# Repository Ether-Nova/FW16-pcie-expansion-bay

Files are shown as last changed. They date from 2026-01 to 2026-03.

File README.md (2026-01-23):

# FW16-pcie-expansion-bay
My goal for this project is to be able to connect any common pcie device to the framework 16. The expansion bay would include 75W power to the gen 4 x8 (4 x16 phisical size) slot and allow pcie extenders and aother devices to be connected to it. 
I am currently in the phase of tesing a covnertor for the 12V 75W bus.

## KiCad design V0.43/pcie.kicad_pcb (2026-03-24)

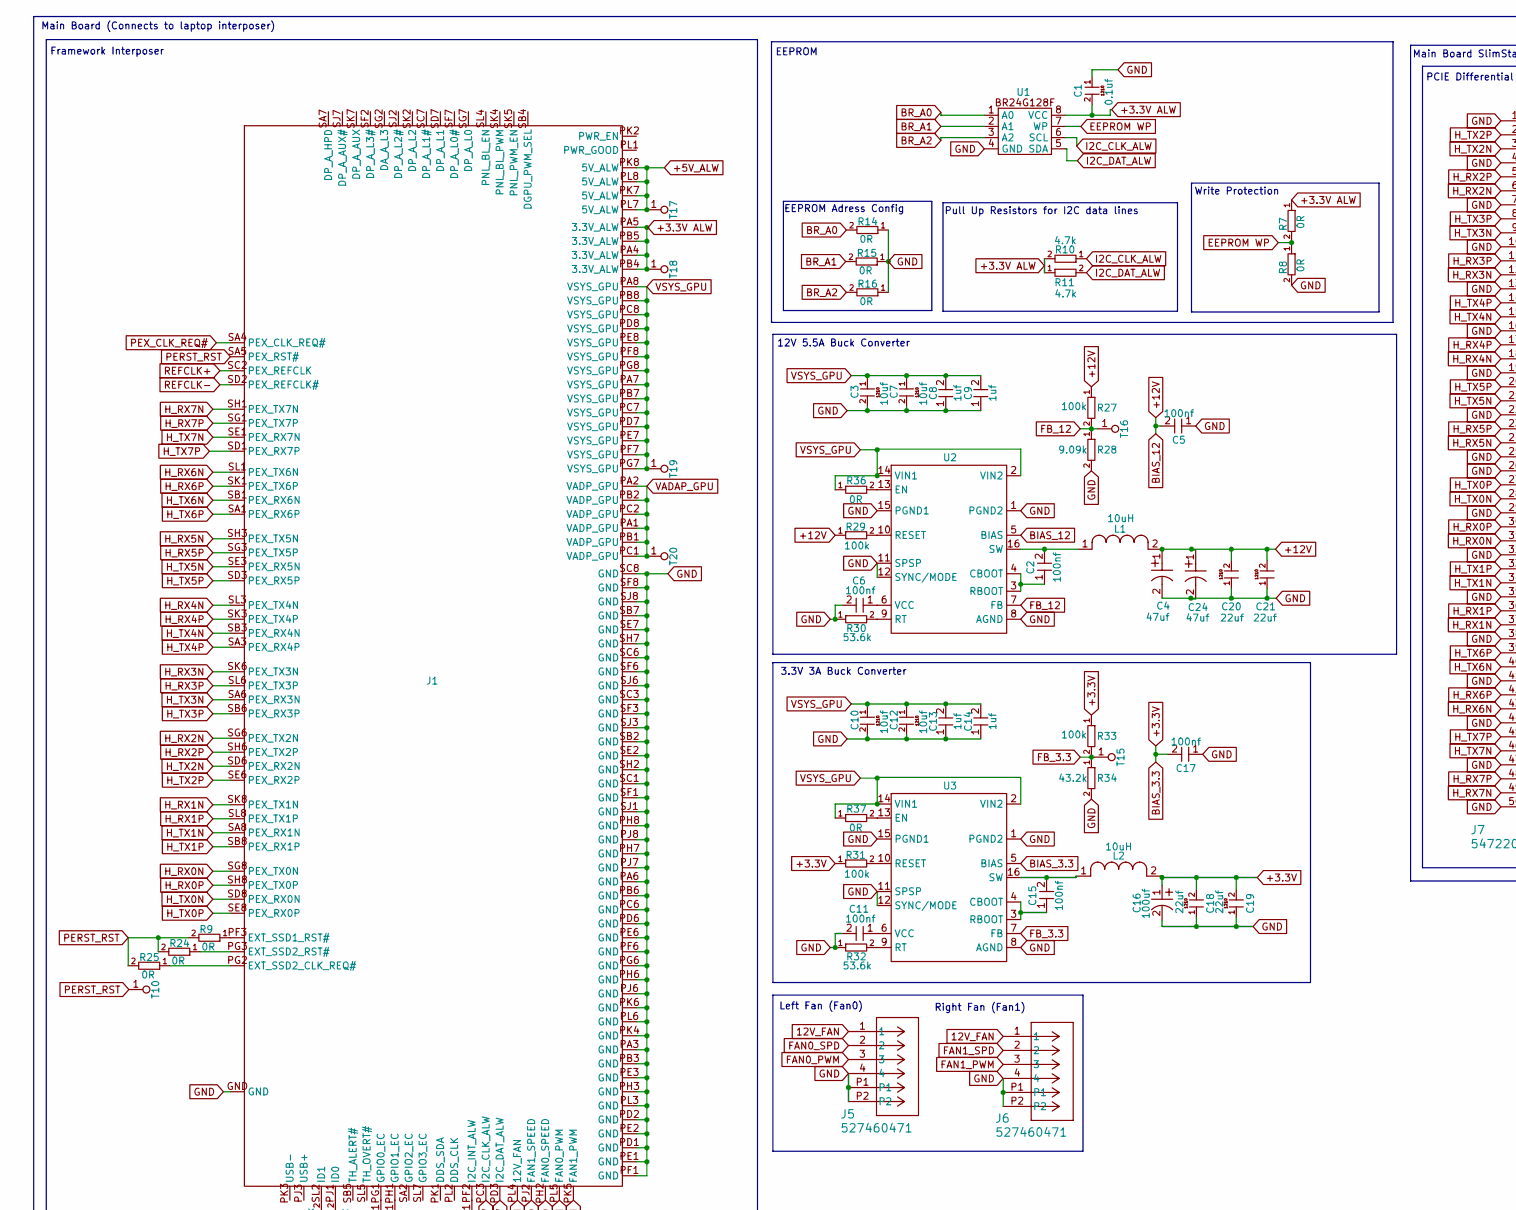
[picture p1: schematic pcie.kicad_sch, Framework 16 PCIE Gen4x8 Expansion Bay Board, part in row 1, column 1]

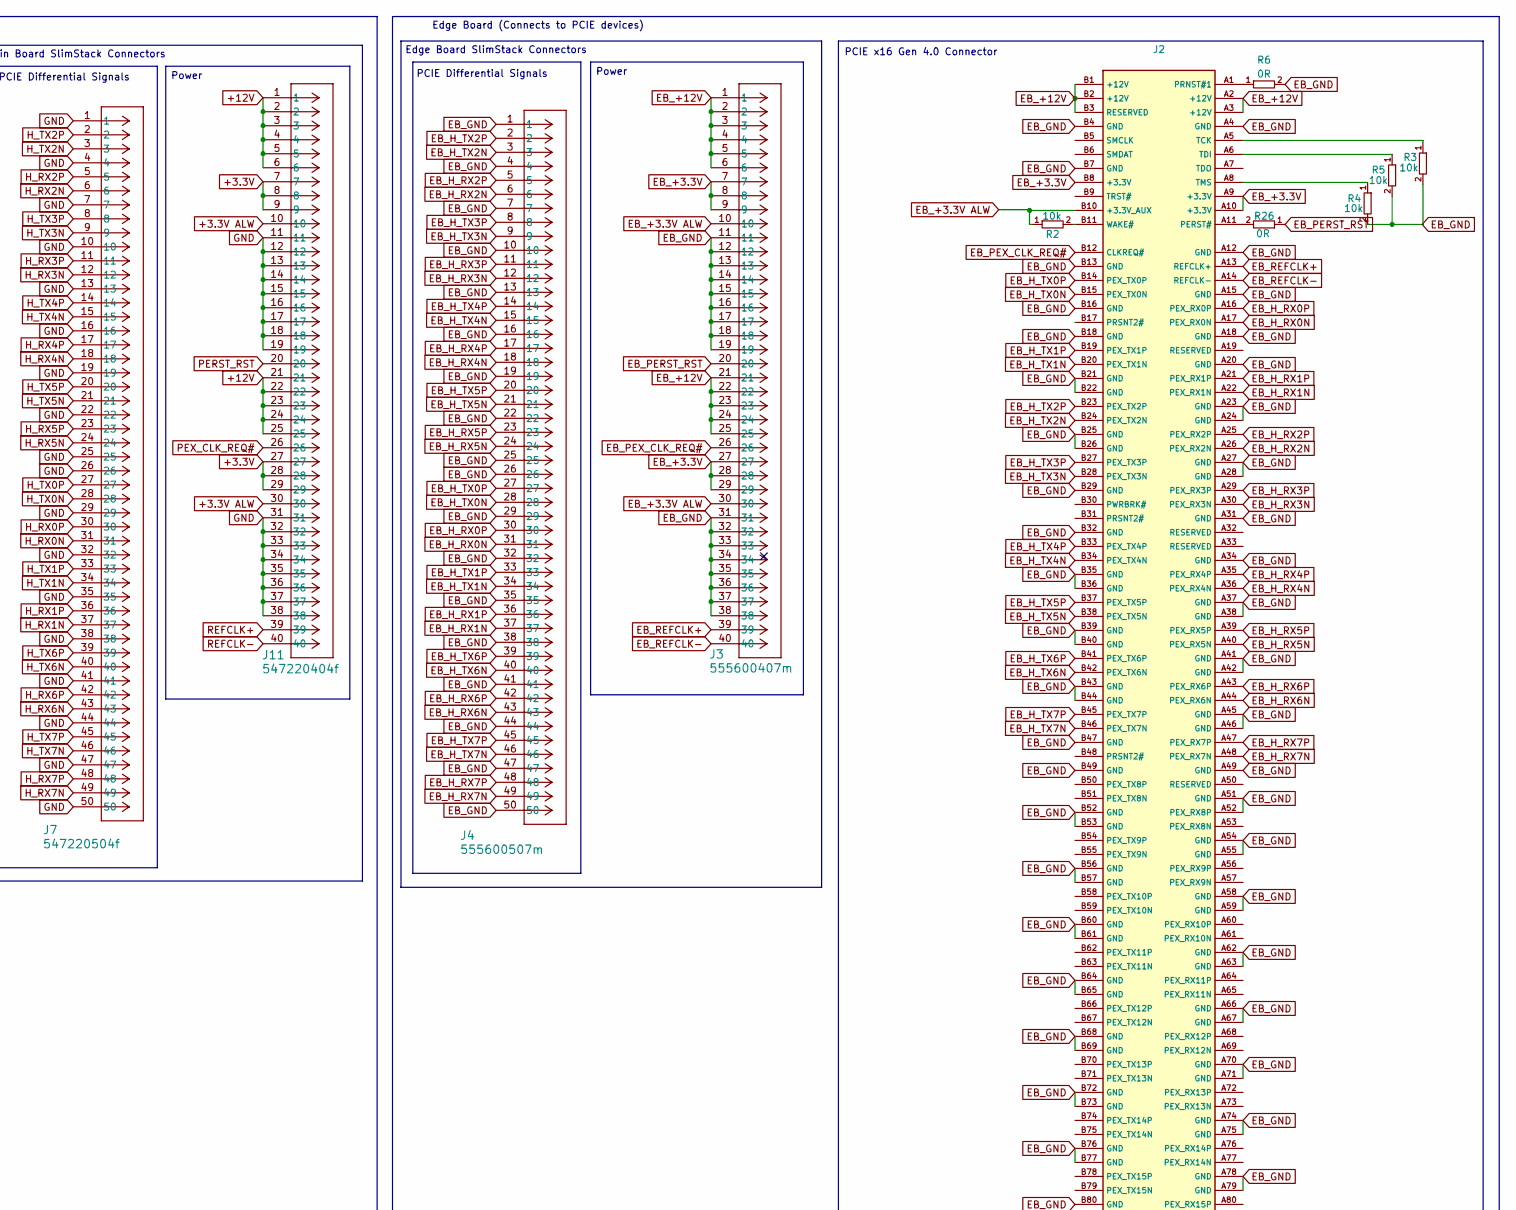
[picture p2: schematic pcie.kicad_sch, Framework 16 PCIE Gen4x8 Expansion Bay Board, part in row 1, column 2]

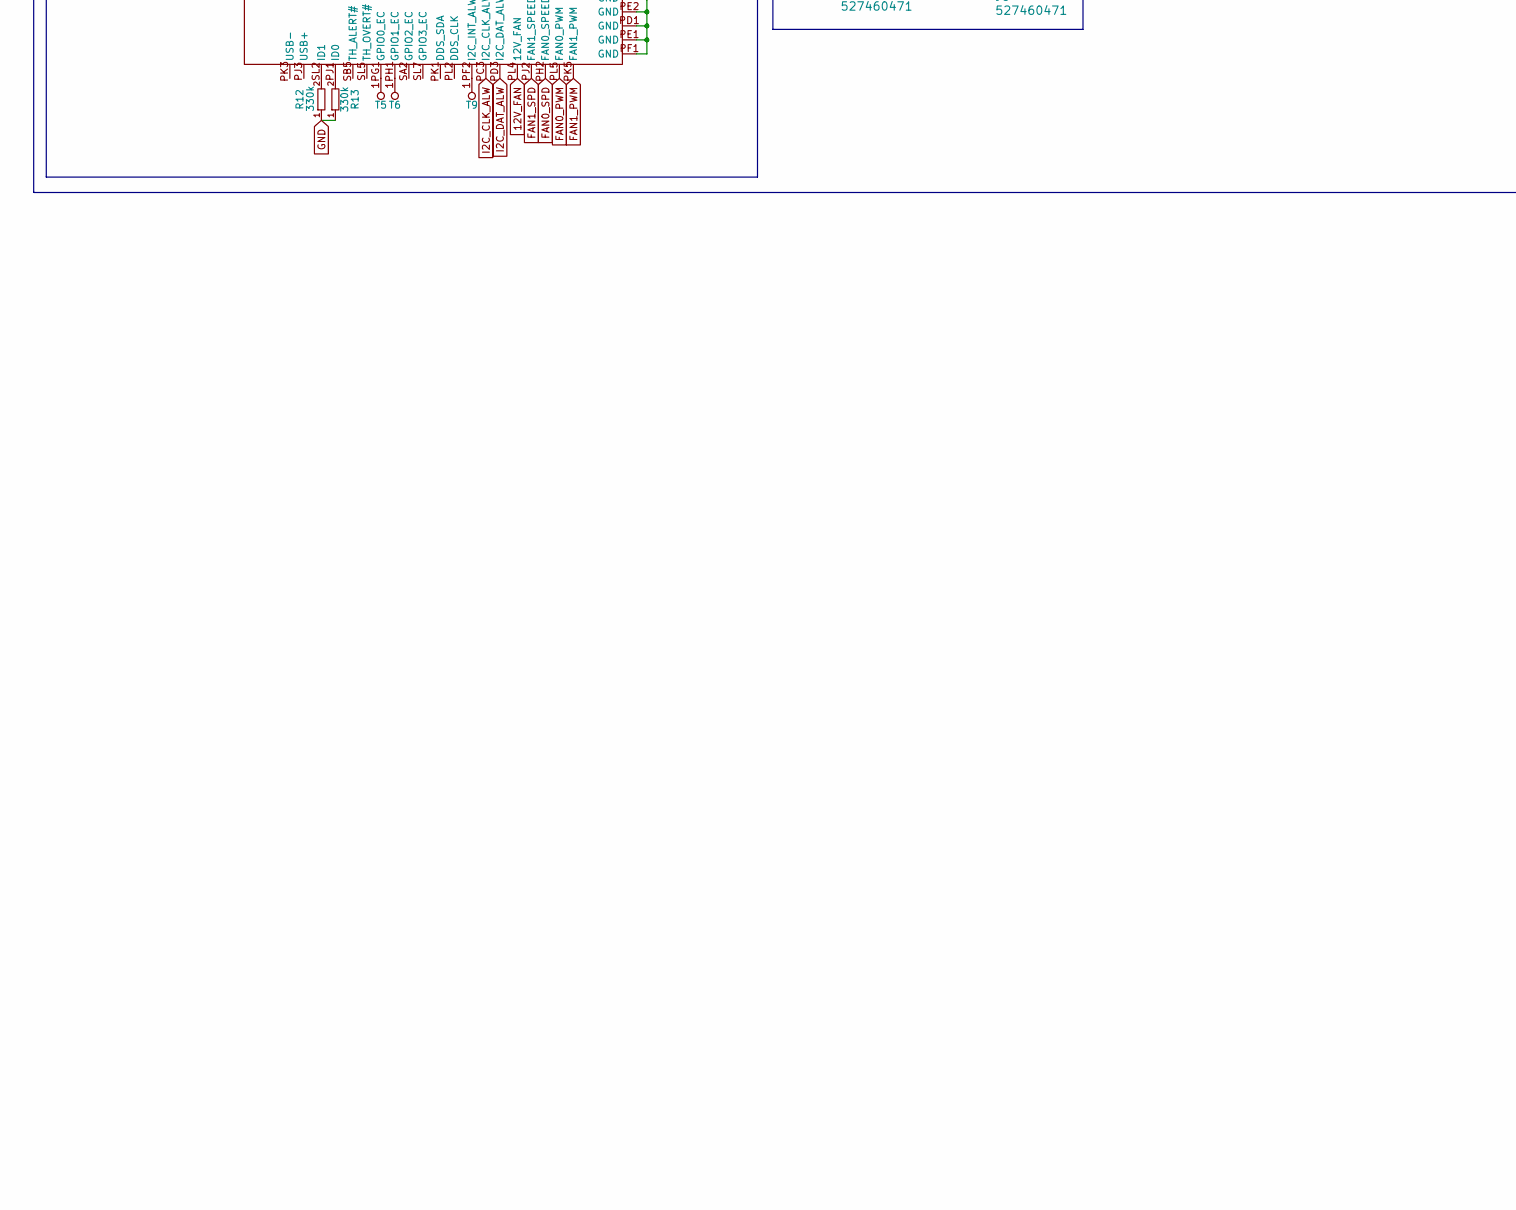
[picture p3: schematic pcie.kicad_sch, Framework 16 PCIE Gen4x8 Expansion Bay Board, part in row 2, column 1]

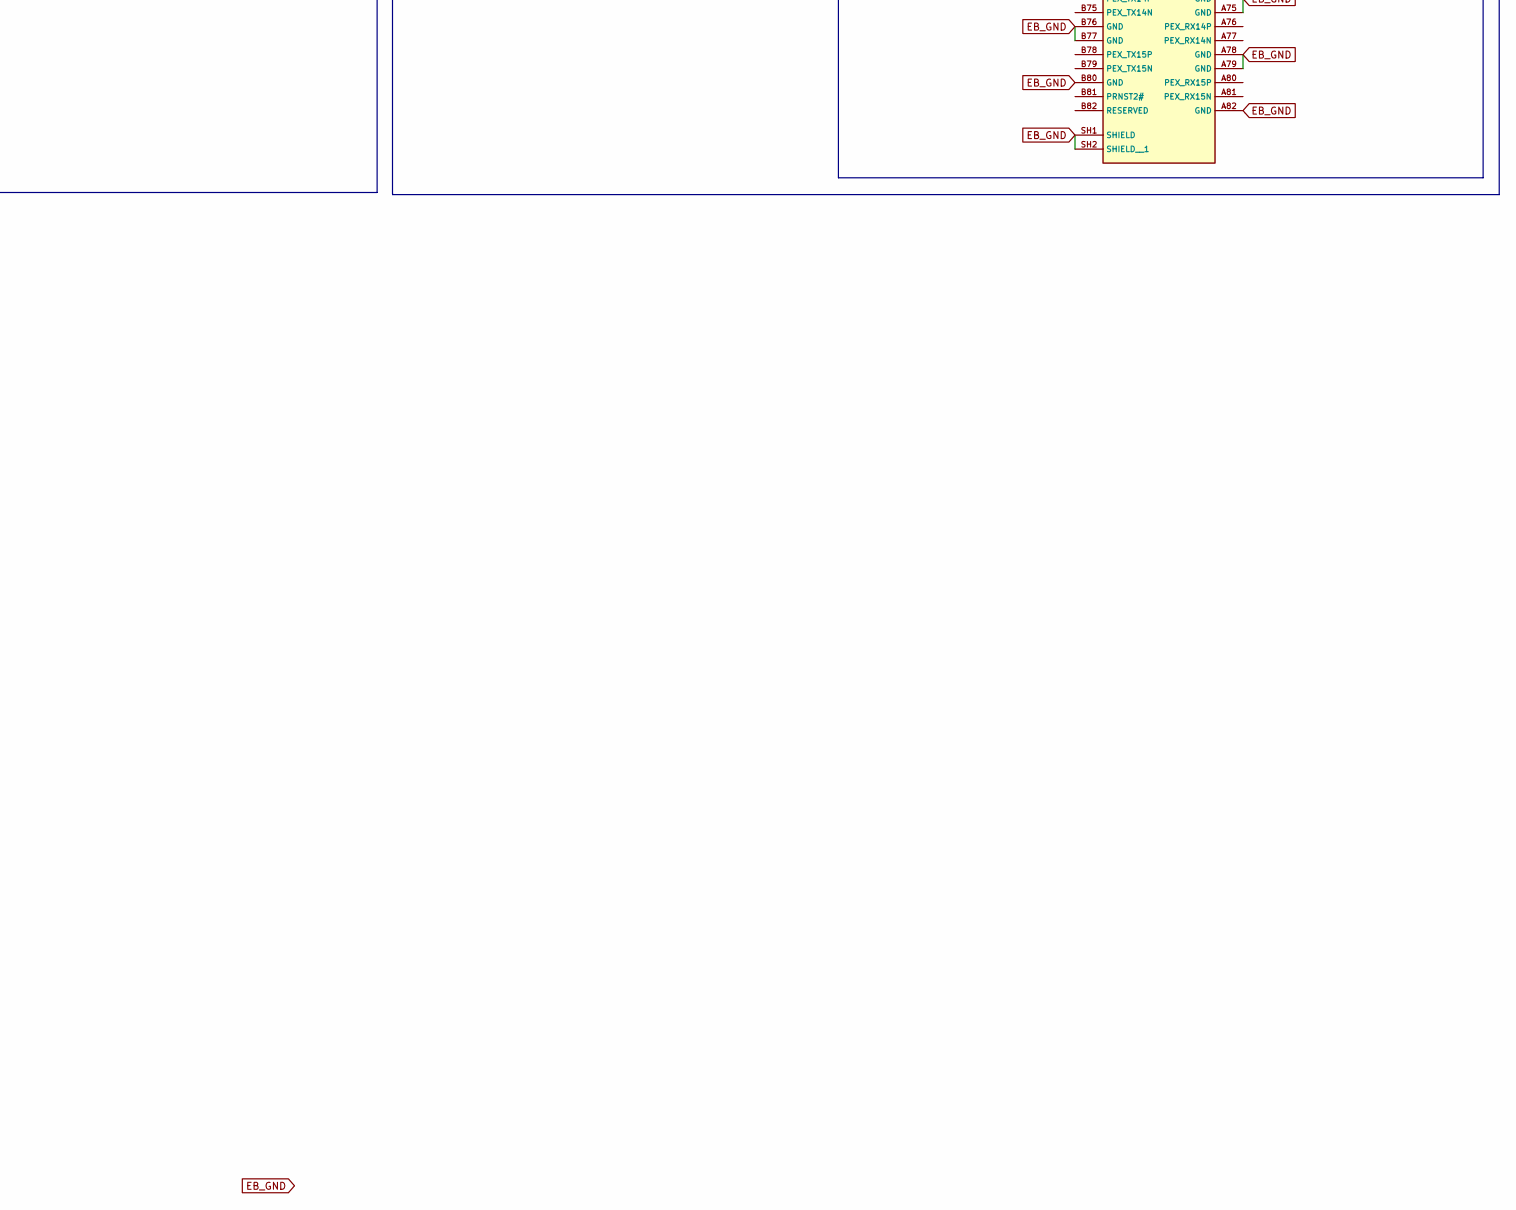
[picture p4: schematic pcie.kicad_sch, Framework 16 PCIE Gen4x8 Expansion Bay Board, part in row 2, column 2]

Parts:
C1: 0.1uf; 1210 capacitor
C2, C5, C6, C11, C15, C17: 100nf; 0603
C3, C7, C10, C12: 10uf; 1210 capacitor
C4, C24: 47uf
C8, C9, C13, C14: 1uf; 0603
C16: 100uf; 100uf (cout)
C18, C19, C20, C21: 22uf; 1210 capacitor
J1: FW 16 Interposer DB
J2: PCIEx16 Edge
J3: 555600407m
J4: 555600507m; CON_555600507m
J5, J6: 527460471; 0527460471
J7: 547220504f; CON_547220504f
J11: 547220404f
L1: 10uH; 10uH (12V)
L2: 10uH; 10uH (3.3V)
R2, R3, R4, R5: 10k; 0603
R6, R7, R8, R9, R14, R15, R16, R24, R25, R26, R36, R37: 0R; 0603
R10, R11: 4.7k; 0603
R12, R13: 330k; 0603
R27, R29, R31, R33: 100k; 0603
R28: 9.09k; 0603
R30, R32: 53.6k; 0603
R34: 43.2k; 0603
T5, T6, T9, T10, T15, T16, T17, T18, T19, T20: TestPad
U1: BR24G128f
U2, U3: LM61480

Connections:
12V_FAN: J1.PL4 (12V_FAN), J5.1, J6.1
+3.3V: C16.1, C17.2, C18.2, C19.2, J11.7, J11.8, J11.9, J11.27, J11.28, J11.29, L2.2, R31.1, R33.1, U3.5 (BIAS)
+3.3V ALW: C1.2, J1.PA4 (3.3V_ALW), J1.PA5 (3.3V_ALW), J1.PB4 (3.3V_ALW), J1.PB5 (3.3V_ALW), J11.10, J11.30, R7.1, R10.2, R11.1, T18.1, U1.8 (VCC)
+5V_ALW: J1.PK7 (5V_ALW), J1.PK8 (5V_ALW), J1.PL7 (5V_ALW), J1.PL8 (5V_ALW), T17.1
+12V: C4.1, C5.2, C20.2, C21.2, C24.1, J11.1, J11.2, J11.3, J11.4, J11.5, J11.6, J11.21, J11.22, J11.23, J11.24, J11.25, L1.2, R27.1, R29.1, U2.5 (BIAS)
BR_A0: R14.2, U1.1 (A0)
BR_A1: R15.2, U1.2 (A1)
BR_A2: R16.2, U1.3 (A2)
EB_+3.3V: J2.A9 (+3.3V), J2.A10 (+3.3V), J2.B8 (+3.3V), J3.7, J3.8, J3.9, J3.27, J3.28, J3.29
EB_+3.3V ALW: J2.B10 (+3.3V_AUX), J3.10, J3.30, R2.1
EB_+12V: J2.A2 (+12V), J2.A3 (+12V), J2.B1 (+12V), J2.B2 (+12V), J2.B3 (RESERVED), J3.1, J3.2, J3.3, J3.4, J3.5, J3.6, J3.21, J3.22, J3.23, J3.24, J3.25
EB_GND: J2.A4 (GND), J2.A12 (GND), J2.A15 (GND), J2.A18 (GND), J2.A20 (GND), J2.A23 (GND), J2.A24 (GND), J2.A27 (GND), J2.A28 (GND), J2.A31 (GND), J2.A34 (GND), J2.A37 (GND), J2.A38 (GND), J2.A41 (GND), J2.A42 (GND), J2.A45 (GND), J2.A46 (GND), J2.A49 (GND), J2.A51 (GND), J2.A52 (PEX_RX8P), J2.A54 (GND), J2.A55 (GND), J2.A58 (GND), J2.A59 (GND), J2.A62 (GND), J2.A63 (GND), J2.A66 (GND), J2.A67 (GND), J2.A70 (GND), J2.A71 (GND), J2.A74 (GND), J2.A75 (GND), J2.A78 (GND), J2.A79 (GND), J2.A82 (GND), J2.B4 (GND), J2.B7 (GND), J2.B13 (GND), J2.B16 (GND), J2.B18 (GND), J2.B21 (GND), J2.B22 (GND), J2.B25 (GND), J2.B26 (GND), J2.B29 (GND), J2.B32 (GND), J2.B35 (GND), J2.B36 (GND), J2.B39 (GND), J2.B40 (GND), J2.B43 (GND), J2.B44 (GND), J2.B47 (GND), J2.B49 (GND), J2.B52 (GND), J2.B53 (GND), J2.B56 (GND), J2.B57 (GND), J2.B60 (GND), J2.B61 (GND), J2.B64 (GND), J2.B65 (GND), J2.B68 (GND), J2.B69 (GND), J2.B72 (GND), J2.B73 (GND), J2.B76 (GND), J2.B77 (GND), J2.B80 (GND), J2.SH1 (SHIELD), J2.SH2 (SHIELD__1), J3.11, J3.12, J3.13, J3.14, J3.15, J3.16, J3.17, J3.18, J3.19, J3.31, J3.32, J3.33, J3.34, J3.35, J3.36, J3.37, J3.38, J4.1, J4.4, J4.7, J4.10, J4.13, J4.16, J4.19, J4.22, J4.25, J4.26, J4.29, J4.32, J4.35, J4.38, J4.41, J4.44, J4.47, J4.50, R3.2, R4.2, R5.2, R6.2
EB_H_RX0N: J2.A17 (PEX_RX0N), J4.31
EB_H_RX0P: J2.A16 (PEX_RX0P), J4.30
EB_H_RX1N: J2.A22 (PEX_RX1N), J4.37
EB_H_RX1P: J2.A21 (PEX_RX1P), J4.36
EB_H_RX2N: J2.A26 (PEX_RX2N), J4.6
EB_H_RX2P: J2.A25 (PEX_RX2P), J4.5
EB_H_RX3N: J2.A30 (PEX_RX3N), J4.12
EB_H_RX3P: J2.A29 (PEX_RX3P), J4.11
EB_H_RX4N: J2.A36 (PEX_RX4N), J4.18
EB_H_RX4P: J2.A35 (PEX_RX4P), J4.17
EB_H_RX5N: J2.A40 (PEX_RX5N), J4.24
EB_H_RX5P: J2.A39 (PEX_RX5P), J4.23
EB_H_RX6N: J2.A44 (PEX_RX6N), J4.43
EB_H_RX6P: J2.A43 (PEX_RX6P), J4.42
EB_H_RX7N: J2.A48 (PEX_RX7N), J4.49
EB_H_RX7P: J2.A47 (PEX_RX7P), J4.48
EB_H_TX0N: J2.B15 (PEX_TX0N), J4.28
EB_H_TX0P: J2.B14 (PEX_TX0P), J4.27
EB_H_TX1N: J2.B20 (PEX_TX1N), J4.34
EB_H_TX1P: J2.B19 (PEX_TX1P), J4.33
EB_H_TX2N: J2.B24 (PEX_TX2N), J4.3
EB_H_TX2P: J2.B23 (PEX_TX2P), J4.2
EB_H_TX3N: J2.B28 (PEX_TX3N), J4.9
EB_H_TX3P: J2.B27 (PEX_TX3P), J4.8
EB_H_TX4N: J2.B34 (PEX_TX4N), J4.15
EB_H_TX4P: J2.B33 (PEX_TX4P), J4.14
EB_H_TX5N: J2.B38 (PEX_TX5N), J4.21
EB_H_TX5P: J2.B37 (PEX_TX5P), J4.20
EB_H_TX6N: J2.B42 (PEX_TX6N), J4.40
EB_H_TX6P: J2.B41 (PEX_TX6P), J4.39
EB_H_TX7N: J2.B46 (PEX_TX7N), J4.46
EB_H_TX7P: J2.B45 (PEX_TX7P), J4.45
EB_PERST_RST: J3.20, R26.1
EB_PEX_CLK_REQ#: J2.B12 (CLKREQ#), J3.26
EB_REFCLK+: J2.A13 (REFCLK+), J3.39
EB_REFCLK-: J2.A14 (REFCLK-), J3.40
EEPROM WP: R7.2, R8.1, U1.7 (WP)
FAN0_PWM: J1.PL5 (FAN0_PWM), J5.3
FAN0_SPD: J1.PH2 (FAN0_SPEED), J5.2
FAN1_PWM: J1.PK5 (FAN1_PWM), J6.3
FAN1_SPD: J1.PJ2 (FAN1_SPEED), J6.2
FB_3.3: R33.2, R34.1, T15.1, U3.7 (FB)
FB_12: R27.2, R28.1, T16.1, U2.7 (FB)
GND: C1.1, C3.2, C4.2, C5.1, C6.2, C7.2, C8.1, C9.1, C10.2, C11.2, C12.2, C13.1, C14.1, C16.2, C17.1, C18.1, C19.1, C20.1, C21.1, C24.2, J1.GND, J1.PA3 (GND), J1.PA6 (GND), J1.PB3 (GND), J1.PB6 (GND), J1.PC6 (GND), J1.PD1 (GND), J1.PD2 (GND), J1.PD6 (GND), J1.PE1 (GND), J1.PE2 (GND), J1.PE3 (GND), J1.PE6 (GND), J1.PF1 (GND), J1.PF6 (GND), J1.PG6 (GND), J1.PH3 (GND), J1.PH6 (GND), J1.PH7 (GND), J1.PH8 (GND), J1.PJ6 (GND), J1.PJ7 (GND), J1.PJ8 (GND), J1.PK4 (GND), J1.PK6 (GND), J1.PL3 (GND), J1.PL6 (GND), J1.SB2 (GND), J1.SB7 (GND), J1.SC1 (GND), J1.SC3 (GND), J1.SC6 (GND), J1.SC8 (GND), J1.SE2 (GND), J1.SE7 (GND), J1.SF1 (GND), J1.SF3 (GND), J1.SF6 (GND), J1.SF8 (GND), J1.SH2 (GND), J1.SH7 (GND), J1.SJ1 (GND), J1.SJ3 (GND), J1.SJ6 (GND), J1.SJ8 (GND), J5.4, J5.P1, J5.P2, J6.4, J6.P1, J6.P2, J7.1, J7.4, J7.7, J7.10, J7.13, J7.16, J7.19, J7.22, J7.25, J7.26, J7.29, J7.32, J7.35, J7.38, J7.41, J7.44, J7.47, J7.50, J11.11, J11.12, J11.13, J11.14, J11.15, J11.16, J11.17, J11.18, J11.19, J11.31, J11.32, J11.33, J11.34, J11.35, J11.36, J11.37, J11.38, R8.2, R12.1, R13.1, R14.1, R15.1, R16.1, R28.2, R30.1, R32.1, R34.2, U1.4 (GND), U2.1 (PGND2), U2.8 (AGND), U2.11 (SPSP), U2.12 (SYNC/MODE), U2.15 (PGND1), U3.1 (PGND2), U3.8 (AGND), U3.11 (SPSP), U3.12 (SYNC/MODE), U3.15 (PGND1)
H_RX0N: J1.SG8 (PEX_TX0N), J7.31
H_RX0P: J1.SH8 (PEX_TX0P), J7.30
H_RX1N: J1.SK8 (PEX_TX1N), J7.37
H_RX1P: J1.SL8 (PEX_TX1P), J7.36
H_RX2N: J1.SG6 (PEX_TX2N), J7.6
H_RX2P: J1.SH6 (PEX_TX2P), J7.5
H_RX3N: J1.SK6 (PEX_TX3N), J7.12
H_RX3P: J1.SL6 (PEX_TX3P), J7.11
H_RX4N: J1.SL3 (PEX_TX4N), J7.18
H_RX4P: J1.SK3 (PEX_TX4P), J7.17
H_RX5N: J1.SH3 (PEX_TX5N), J7.24
H_RX5P: J1.SG3 (PEX_TX5P), J7.23
H_RX6N: J1.SL1 (PEX_TX6N), J7.43
H_RX6P: J1.SK1 (PEX_TX6P), J7.42
H_RX7N: J1.SH1 (PEX_TX7N), J7.49
H_RX7P: J1.SG1 (PEX_TX7P), J7.48
H_TX0N: J1.SD8 (PEX_RX0N), J7.28
H_TX0P: J1.SE8 (PEX_RX0P), J7.27
H_TX1N: J1.SA8 (PEX_RX1N), J7.34
H_TX1P: J1.SB8 (PEX_RX1P), J7.33
H_TX2N: J1.SD6 (PEX_RX2N), J7.3
H_TX2P: J1.SE6 (PEX_RX2P), J7.2
H_TX3N: J1.SA6 (PEX_RX3N), J7.9
H_TX3P: J1.SB6 (PEX_RX3P), J7.8
H_TX4N: J1.SB3 (PEX_RX4N), J7.15
H_TX4P: J1.SA3 (PEX_RX4P), J7.14
H_TX5N: J1.SE3 (PEX_RX5N), J7.21
H_TX5P: J1.SD3 (PEX_RX5P), J7.20
H_TX6N: J1.SB1 (PEX_RX6N), J7.40
H_TX6P: J1.SA1 (PEX_RX6P), J7.39
H_TX7N: J1.SE1 (PEX_RX7N), J7.46
H_TX7P: J1.SD1 (PEX_RX7P), J7.45
I2C_CLK_ALW: J1.PC3 (I2C_CLK_ALW), R10.1, U1.6 (SCL)
I2C_DAT_ALW: J1.PD3 (I2C_DAT_ALW), R11.2, U1.5 (SDA)
unnamed: J1.PF3 (EXT_SSD1_RST#), R9.1
unnamed: J1.PG2 (EXT_SSD2_CLK_REQ#), R25.1
unnamed: J1.PG3 (EXT_SSD2_RST#), R24.1
unnamed: J1.PG1 (GPIO0_EC), T5.1
unnamed: J1.PH1 (GPIO1_EC), T6.1
unnamed: J1.PF2 (I2C_INT_ALW), T9.1
unnamed: J1.PJ1 (ID0), R13.2
unnamed: J1.SL2 (ID1), R12.2
unnamed: J2.A11 (PERST#), R26.2
unnamed: J2.A1 (PRNST#1), R6.1
unnamed: J2.A5 (TCK), R3.1
unnamed: J2.A6 (TDI), R5.1
unnamed: J2.A8 (TMS), R4.1
unnamed: J2.B11 (WAKE#), R2.2
unnamed: C2.1, U2.3 (RBOOT), U2.4 (CBOOT)
unnamed: R36.2, U2.13 (EN)
unnamed: R29.2, U2.10 (RESET)
unnamed: R30.2, U2.9 (RT)
unnamed: C2.2, L1.1, U2.16 (SW)
unnamed: C6.1, U2.6 (VCC)
unnamed: C15.1, U3.3 (RBOOT), U3.4 (CBOOT)
unnamed: R37.2, U3.13 (EN)
unnamed: R31.2, U3.10 (RESET)
unnamed: R32.2, U3.9 (RT)
unnamed: C15.2, L2.1, U3.16 (SW)
unnamed: C11.1, U3.6 (VCC)
PERST_RST: J1.SA5 (PEX_RST#), J11.20, R9.2, R24.2, R25.2, T10.1
PEX_CLK_REQ#: J1.SA4 (PEX_CLK_REQ#), J11.26
REFCLK+: J1.SC2 (PEX_REFCLK), J11.39
REFCLK-: J1.SD2 (PEX_REFCLK#), J11.40
VADAP_GPU: J1.PA1 (VADP_GPU), J1.PA2 (VADP_GPU), J1.PB1 (VADP_GPU), J1.PB2 (VADP_GPU), J1.PC1 (VADP_GPU), J1.PC2 (VADP_GPU), T20.1
VSYS_GPU: C3.1, C7.1, C8.2, C9.2, C10.1, C12.1, C13.2, C14.2, J1.PA7 (VSYS_GPU), J1.PA8 (VSYS_GPU), J1.PB7 (VSYS_GPU), J1.PB8 (VSYS_GPU), J1.PC7 (VSYS_GPU), J1.PC8 (VSYS_GPU), J1.PD7 (VSYS_GPU), J1.PD8 (VSYS_GPU), J1.PE7 (VSYS_GPU), J1.PE8 (VSYS_GPU), J1.PF7 (VSYS_GPU), J1.PF8 (VSYS_GPU), J1.PG7 (VSYS_GPU), J1.PG8 (VSYS_GPU), R36.1, R37.1, T19.1, U2.2 (VIN2), U2.14 (VIN1), U3.2 (VIN2), U3.14 (VIN1)

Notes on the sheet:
Pull Up Resistors for I2C data lines
PCIE x16 Gen 4.0 Connector
Write Protection
PCIE Differential Signals
EEPROM Adress Config
Main Board (Connects to laptop interposer)
3.3V 3A Buck Converter
Right Fan (Fan1)
Edge Board SlimStack Connectors
Main Board SlimStack Connectors
Edge Board (Connects to PCIE devices)
12V 5.5A Buck Converter
Framework Interposer
EEPROM
Left Fan (Fan0)
Power

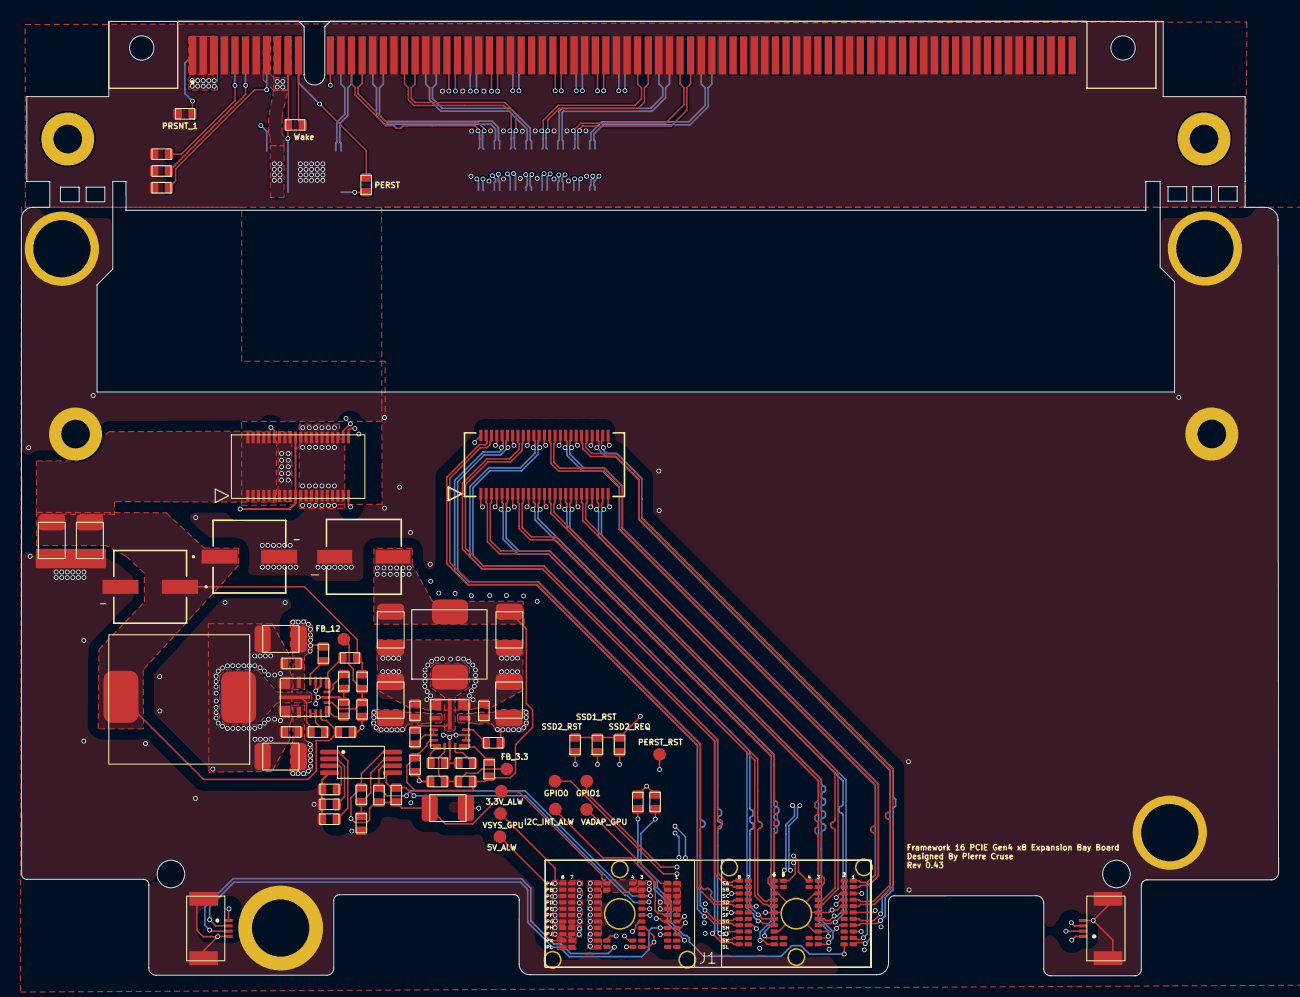
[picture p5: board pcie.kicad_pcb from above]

Board: 4 copper layers, 118.6 x 90.0 mm, 73 parts (0 on the bottom side), 122 nets.

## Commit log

2025-06-17 Add files via upload
    V0.2
    [Interposer to PCIEx16.kicad_pcb, Interposer to PCIEx16.kicad_sch]
2025-08-15 New PCB design
    [pcie-B_Cu.gbr, pcie-B_Mask.gbr, pcie-B_Paste.gbr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]
2026-01-15 V0.4 Added
    [pcie.kicad_pcb, pcie.kicad_sch]
2026-01-22 v0.42
    Fixed interposer footprint and cleaned up schematic
    [pcie.kicad_sch]
2026-03-24 V0.43
    Changed board-board connectors to ones that are easier to solder by hand
    [pcie.kicad_pcb, pcie.kicad_sch]
